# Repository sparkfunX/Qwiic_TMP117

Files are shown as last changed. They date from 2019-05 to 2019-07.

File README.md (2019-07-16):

SparkX Qwiic TMP117
========================================

SparkX High Precision Temperature Sensor - TMP117 (https://www.sparkfun.com/products/15413)

[*High Precision Temperature Sensor - TMP117 (Qwiic) (SPX-15413)*](https://www.sparkfun.com/products/15413)

The TMP117 is a high precision temperature Sensor with accuracy of up to +/-0.1 degrees celsius and an operating temperature range of -55°C to +150°C. It is NIST traceable and verified with equipment that is calibrated to ISO/IEC 17025 accredited standards. It has a very low power consumption with a supply range of 1.8V to 5.5V. 

The TMP117 address can be changed with an external jumper to 4 different addresses. There are 4 different conversion modes that it can read from, with continuous conversion, shutdown, and one shot conversion. There is also digital offset for system correction, programmable temperature limits, General-Purpose EEPROM, and selectable averaging. 

Repository Contents
-------------------

* **/Documents** - Data sheet for the TMP117
* **/Hardware** - Eagle design files (.brd, .sch)
* **/Production** - Production panel files (.brd) within the Production folder

License Information
-------------------

This product is _**open source**_! 

Please review the LICENSE.md file for license information. 

If you have any questions or concerns on licensing, please contact technical support on our [SparkFun forums](https://forum.sparkfun.com/viewforum.php?f=152).

Distributed as-is; no warranty is given.

- Your friends at SparkFun.

_<COLLABORATION CREDIT>_

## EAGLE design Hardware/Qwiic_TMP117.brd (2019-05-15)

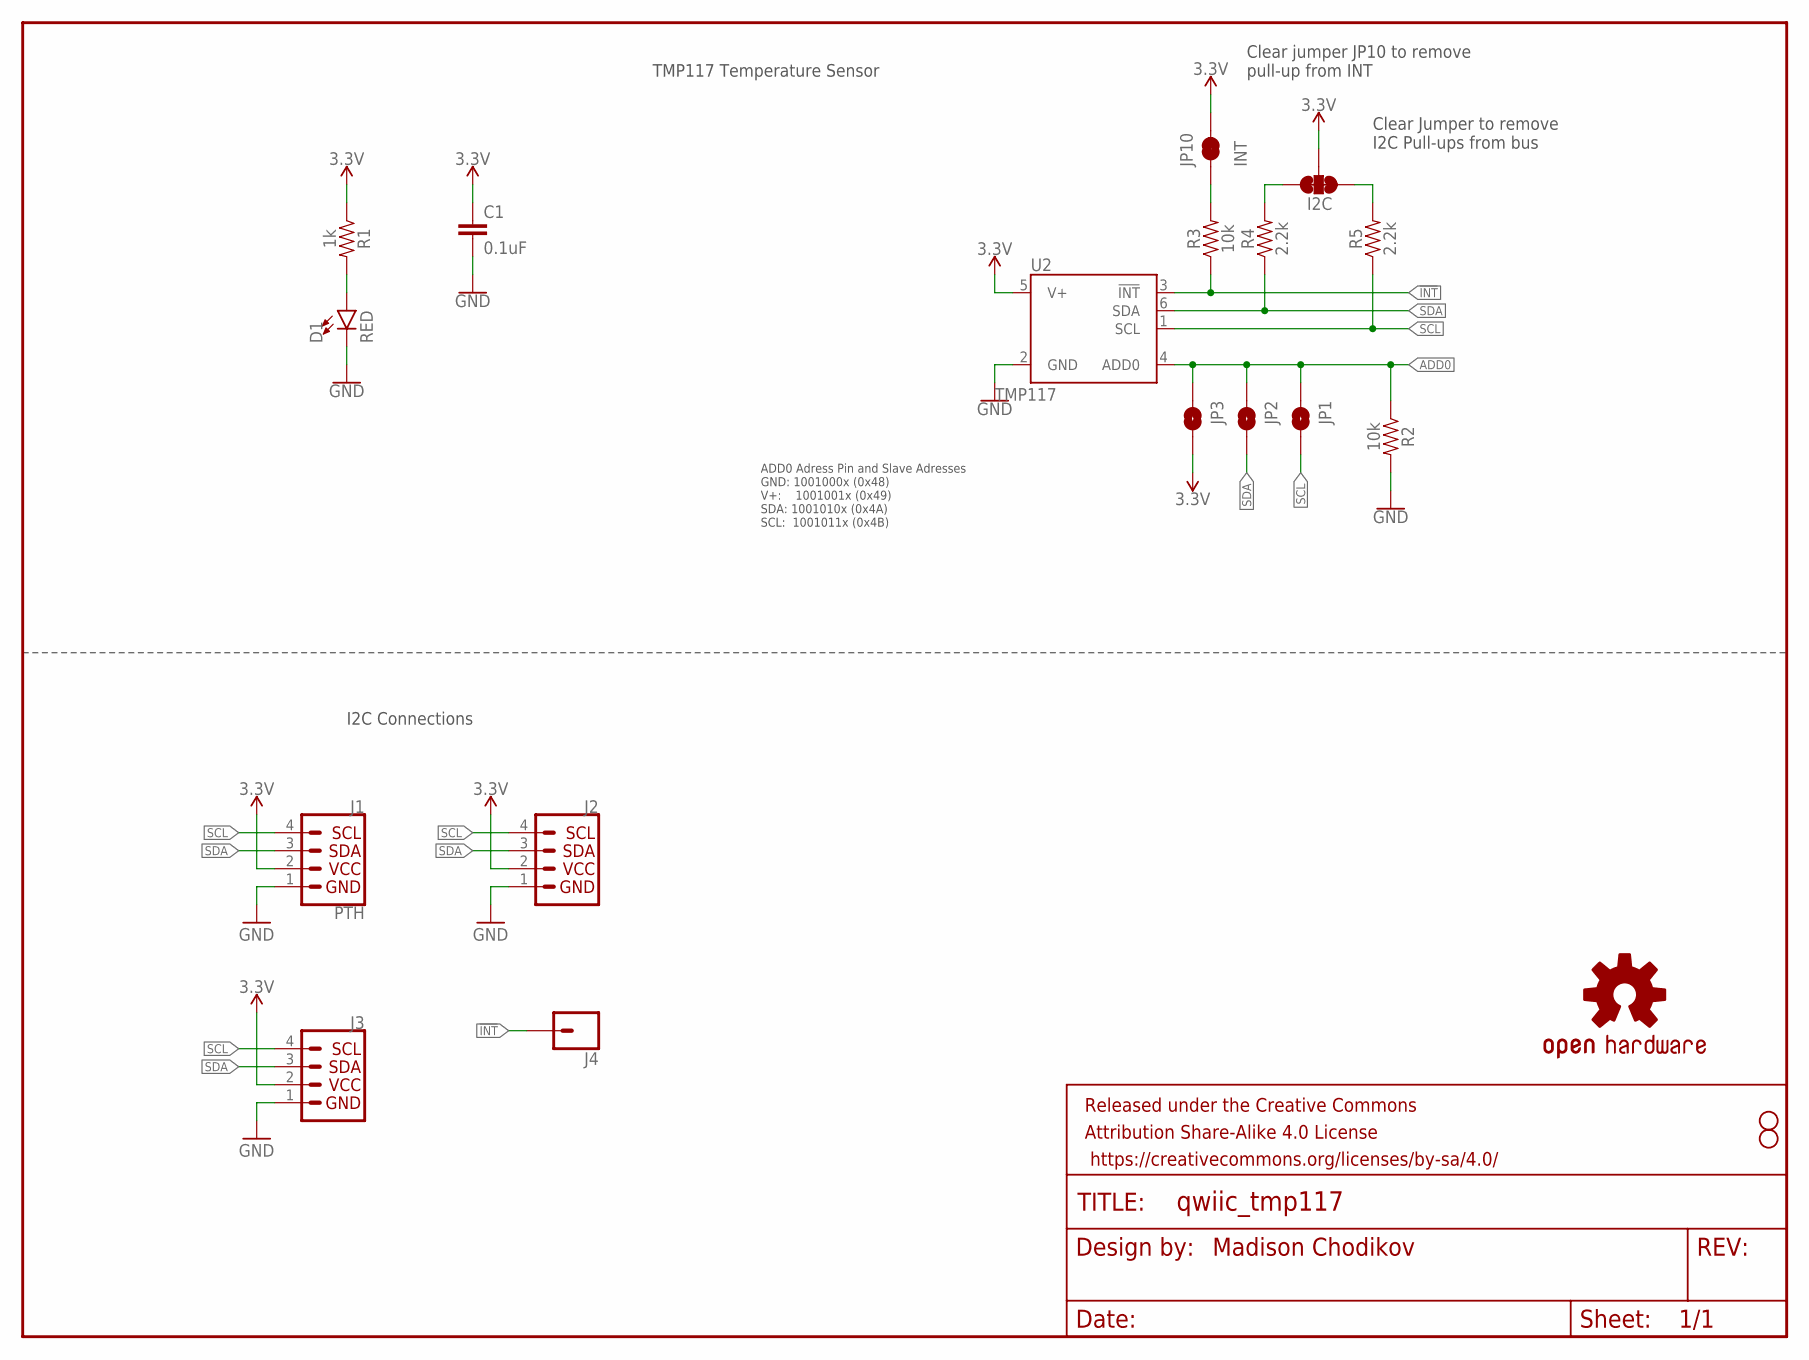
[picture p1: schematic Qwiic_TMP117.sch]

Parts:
C1: 0.1uF; 0603
D1: RED; LED-0603
FRAME1: FRAME-LETTER; CREATIVE_COMMONS
I2C: JUMPER-SMT_3_2-NC_TRACE_SILK; SMT-JUMPER_3_2-NC_TRACE_SILK
J1: PTH; 1X04_NO_SILK
J2, J3: QWIIC_CONNECTORJS-1MM; JST04_1MM_RA
J4: CONN_01PTH_NO_SILK_YES_STOP; 1X01_NO_SILK
JP1, JP2, JP3: JUMPER-SMT_2_NO_SILK; SMT-JUMPER_2_NO_SILK
JP8, JP9: STAND-OFF
JP10: INT; PAD-JUMPER-2-NC_BY_TRACE_YES_SILK
LOGO1: OSHW-LOGOMINI; OSHW-LOGO-MINI
R1: 1k; 0603
R2, R3: 10k; 0603
R4, R5: 2.2k; 0603
U2: TMP117

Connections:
3.3V: C1.1, I2C.2, J1.2 (VCC), J2.2, J3.2, JP3.2, JP10.2, R1.1, U2.5 (V+)
!INT: J4.1, R3.1, U2.3 (!INT)
ADD0: JP1.1, JP2.1, JP3.1, R2.1, U2.4 (ADD0)
GND: C1.2, D1.C, J1.1 (GND), J2.1, J3.1, R2.2, U2.2 (GND)
unnamed: D1.A, R1.2
unnamed: I2C.1, R5.2
unnamed: I2C.3, R4.2
unnamed: JP10.1, R3.2
SCL: J1.4 (SCL), J2.4, J3.4, JP1.2, R5.1, U2.1 (SCL)
SDA: J1.3 (SDA), J2.3, J3.3, JP2.2, R4.1, U2.6 (SDA)

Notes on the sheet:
I2C Connections
TMP117 Temperature Sensor
Madison Chodikov
Clear Jumper to remove I2C Pull-ups from bus
Clear jumper JP10 to remove pull-up from INT
ADD0 Adress Pin and Slave Adresses GND: 1001000x (0x48) V+: 1001001x (0x49) SDA: 1001010x (0x4A) SCL: 1001011x (0x4B)

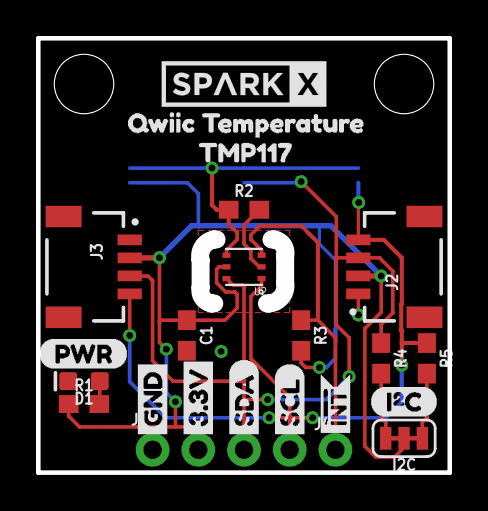
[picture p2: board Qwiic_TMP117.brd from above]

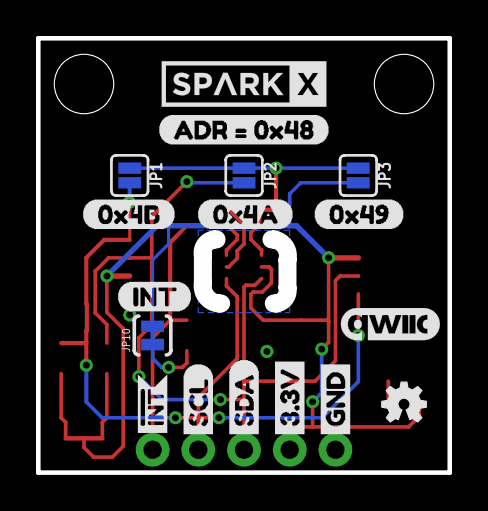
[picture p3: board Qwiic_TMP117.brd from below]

Board: 2 copper layers, 22.9 x 24.1 mm, 43 parts (17 on the bottom side), 10 nets.

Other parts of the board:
U$1: 0X4B1
U$2, U$17: SPARKX-MEDIUM
U$3, U$11: INT#-[<-04
U$4: TMP1171
U$5: 0X4A0
U$6: QWIIC_TEMPERATURE2
U$7: INT-()-04
U$8: 0X493
U$9, U$12: SCL-[)
U$10, U$23: GND-04
U$13, U$14: SDA-[)
U$15: QWIIC_5.5MM
U$18: ADR_#_0X484
U$19, U$22: 3.3V
U$20: PWR-()-04
U$21: I_SUPER2_C-()-04

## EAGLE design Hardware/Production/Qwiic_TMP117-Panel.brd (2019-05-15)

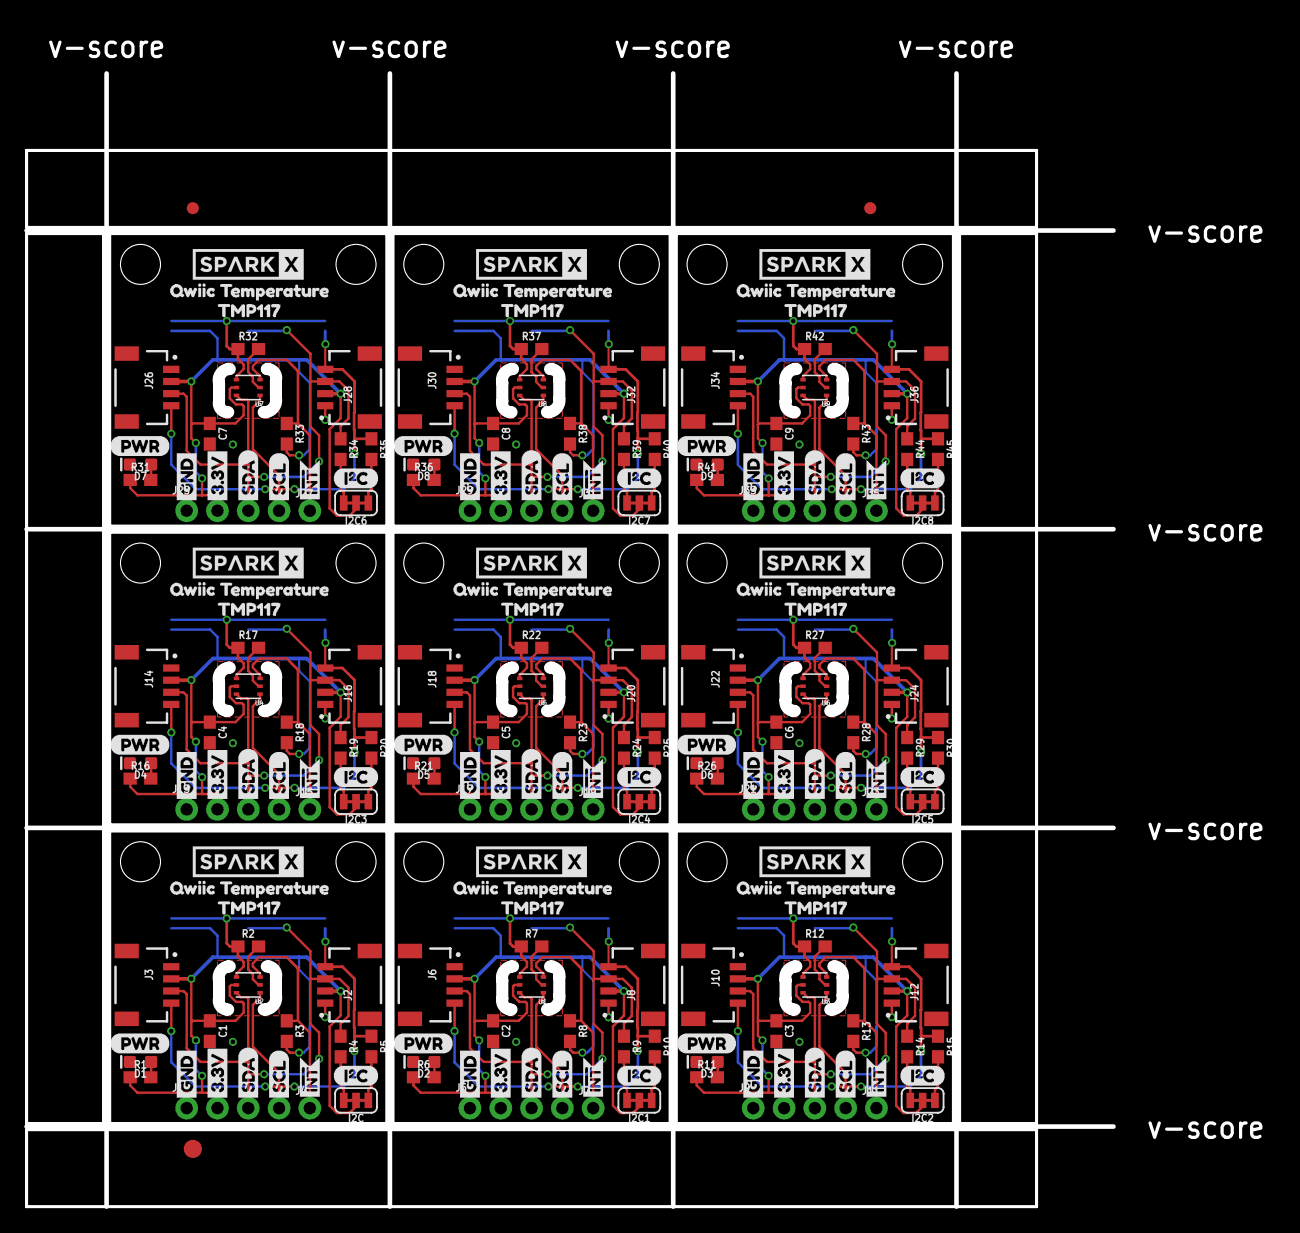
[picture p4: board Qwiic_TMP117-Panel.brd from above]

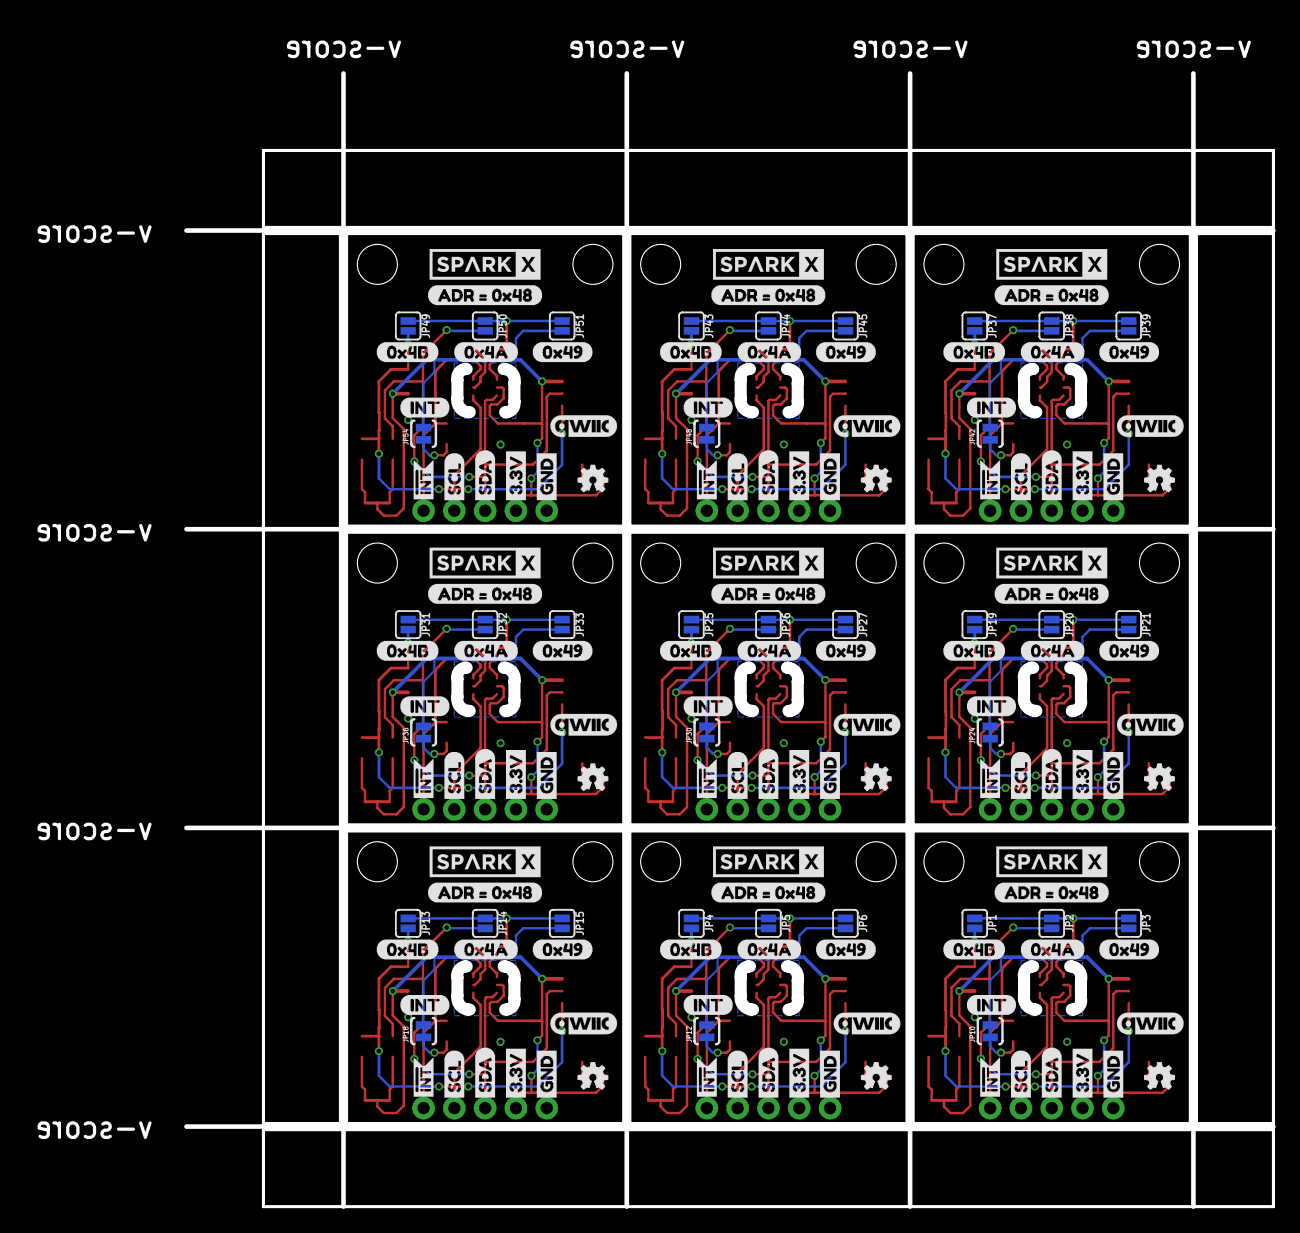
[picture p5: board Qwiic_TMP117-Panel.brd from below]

Board: 2 copper layers, 89.7 x 93.5 mm, 381 parts (153 on the bottom side), 90 nets.

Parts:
C1, C2, C3, C4, C5, C6, C7, C8, C9: 0.1uF; 0603
D1, D2, D3, D4, D5, D6, D7, D8, D9: RED; LED-0603
E$1, E$2: FIDUCIAL-1X2
E$3: FIDUCIAL-1.5X3
I2C, I2C1, I2C2, I2C3, I2C4, I2C5, I2C6, I2C7, I2C8: SMT-JUMPER_3_2-NC_TRACE_SILK
J1, J5, J9, J13, J17, J21, J25, J29, J33: PTH; 1X04_NO_SILK
J2, J3, J6, J8, J10, J12, J14, J16, J18, J20, J22, J24, J26, J28, J30, J32, J34, J36: JST04_1MM_RA
J4, J7, J11, J15, J19, J23, J27, J31, J35: 1X01_NO_SILK
JP1, JP2, JP3, JP4, JP5, JP6, JP13, JP14, JP15, JP19, JP20, JP21, JP25, JP26, JP27, JP31, JP32, JP33, JP37, JP38, JP39, JP43, JP44, JP45, JP49, JP50, JP51: SMT-JUMPER_2_NO_SILK
JP7, JP8, JP9, JP11, JP16, JP17, JP22, JP23, JP28, JP29, JP34, JP35, JP40, JP41, JP46, JP47, JP52, JP53: STAND-OFF
JP10, JP12, JP18, JP24, JP30, JP36, JP42, JP48, JP54: INT; PAD-JUMPER-2-NC_BY_TRACE_YES_SILK
LOGO1, LOGO2, LOGO3, LOGO4, LOGO5, LOGO6, LOGO7, LOGO8, LOGO9: OSHW-LOGOMINI; OSHW-LOGO-MINI
R1, R6, R11, R16, R21, R26, R31, R36, R41: 1k; 0603
R2, R3, R7, R8, R12, R13, R17, R18, R22, R23, R27, R28, R32, R33, R37, R38, R42, R43: 10k; 0603
R4, R5, R9, R10, R14, R15, R19, R20, R24, R25, R29, R30, R34, R35, R39, R40, R44, R45: 2.2k; 0603
U1, U2, U3, U4, U5, U6, U7, U8, U9: TMP117
U$1, U$40, U$62, U$84, U$106, U$128, U$150, U$172, U$194: 0X4B1
U$2, U$17, U$25, U$26, U$47, U$48, U$69, U$70, U$91, U$92, U$113, U$114, U$135, U$136, U$157, U$158, U$179, U$180: SPARKX-MEDIUM
U$3, U$11, U$27, U$30, U$49, U$52, U$71, U$74, U$93, U$96, U$115, U$118, U$137, U$140, U$159, U$162, U$181, U$184: INT#-[<-04
U$4, U$16, U$45, U$67, U$89, U$111, U$133, U$155, U$177: TMP1171
U$5, U$41, U$63, U$85, U$107, U$129, U$151, U$173, U$195: 0X4A0
U$6, U$24, U$46, U$68, U$90, U$112, U$134, U$156, U$178: QWIIC_TEMPERATURE2
U$7, U$28, U$50, U$72, U$94, U$116, U$138, U$160, U$182: INT-()-04
U$8, U$42, U$64, U$86, U$108, U$130, U$152, U$174, U$196: 0X493
U$9, U$12, U$29, U$37, U$51, U$59, U$73, U$81, U$95, U$103, U$117, U$125, U$139, U$147, U$161, U$169, U$183, U$191: SCL-[)
U$10, U$23, U$35, U$36, U$57, U$58, U$79, U$80, U$101, U$102, U$123, U$124, U$145, U$146, U$167, U$168, U$189, U$190: GND-04
U$13, U$14, U$38, U$39, U$60, U$61, U$82, U$83, U$104, U$105, U$126, U$127, U$148, U$149, U$170, U$171, U$192, U$193: SDA-[)
U$15, U$44, U$66, U$88, U$110, U$132, U$154, U$176, U$198: QWIIC_5.5MM
U$18, U$43, U$65, U$87, U$109, U$131, U$153, U$175, U$197: ADR_#_0X484
U$19, U$22, U$33, U$34, U$55, U$56, U$77, U$78, U$99, U$100, U$121, U$122, U$143, U$144, U$165, U$166, U$187, U$188: 3.3V
U$20, U$31, U$53, U$75, U$97, U$119, U$141, U$163, U$185: PWR-()-04
U$21, U$32, U$54, U$76, U$98, U$120, U$142, U$164, U$186: I_SUPER2_C-()-04

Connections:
3.3V: C1.1, I2C.2, J1.2, J2.2, J3.2, JP3.2, JP10.2, R1.1, U2.5
3.3V1: C2.1, I2C1.2, J5.2, J6.2, J8.2, JP6.2, JP12.2, R6.1, U1.5
3.3V2: C3.1, I2C2.2, J9.2, J10.2, J12.2, JP15.2, JP18.2, R11.1, U3.5
3.3V3: C4.1, I2C3.2, J13.2, J14.2, J16.2, JP21.2, JP24.2, R16.1, U4.5
3.3V4: C5.1, I2C4.2, J17.2, J18.2, J20.2, JP27.2, JP30.2, R21.1, U5.5
3.3V5: C6.1, I2C5.2, J21.2, J22.2, J24.2, JP33.2, JP36.2, R26.1, U6.5
3.3V6: C7.1, I2C6.2, J25.2, J26.2, J28.2, JP39.2, JP42.2, R31.1, U7.5
3.3V7: C8.1, I2C7.2, J29.2, J30.2, J32.2, JP45.2, JP48.2, R36.1, U8.5
3.3V8: C9.1, I2C8.2, J33.2, J34.2, J36.2, JP51.2, JP54.2, R41.1, U9.5
!INT: J4.1, R3.1, U2.3
!INT1: J7.1, R8.1, U1.3
!INT2: J11.1, R13.1, U3.3
!INT3: J15.1, R18.1, U4.3
!INT4: J19.1, R23.1, U5.3
!INT5: J23.1, R28.1, U6.3
!INT6: J27.1, R33.1, U7.3
!INT7: J31.1, R38.1, U8.3
!INT8: J35.1, R43.1, U9.3
ADD0: JP1.1, JP2.1, JP3.1, R2.1, U2.4
ADD1: JP4.1, JP5.1, JP6.1, R7.1, U1.4
ADD2: JP13.1, JP14.1, JP15.1, R12.1, U3.4
ADD3: JP19.1, JP20.1, JP21.1, R17.1, U4.4
ADD4: JP25.1, JP26.1, JP27.1, R22.1, U5.4
ADD5: JP31.1, JP32.1, JP33.1, R27.1, U6.4
ADD6: JP37.1, JP38.1, JP39.1, R32.1, U7.4
ADD7: JP43.1, JP44.1, JP45.1, R37.1, U8.4
ADD8: JP49.1, JP50.1, JP51.1, R42.1, U9.4
GND: C1.2, D1.C, J1.1, J2.1, J3.1, R2.2, U2.2
GND1: C2.2, D2.C, J5.1, J6.1, J8.1, R7.2, U1.2
GND2: C3.2, D3.C, J9.1, J10.1, J12.1, R12.2, U3.2
GND3: C4.2, D4.C, J13.1, J14.1, J16.1, R17.2, U4.2
GND4: C5.2, D5.C, J17.1, J18.1, J20.1, R22.2, U5.2
GND5: C6.2, D6.C, J21.1, J22.1, J24.1, R27.2, U6.2
GND6: C7.2, D7.C, J25.1, J26.1, J28.1, R32.2, U7.2
GND7: C8.2, D8.C, J29.1, J30.1, J32.1, R37.2, U8.2
GND8: C9.2, D9.C, J33.1, J34.1, J36.1, R42.2, U9.2
unnamed: D1.A, R1.2
unnamed: I2C.1, R5.2
unnamed: I2C.3, R4.2
unnamed: JP10.1, R3.2
unnamed: D2.A, R6.2
unnamed: I2C1.1, R10.2
unnamed: I2C1.3, R9.2
unnamed: JP12.1, R8.2
unnamed: D3.A, R11.2
unnamed: I2C2.1, R15.2
unnamed: I2C2.3, R14.2
unnamed: JP18.1, R13.2
unnamed: D4.A, R16.2
unnamed: I2C3.1, R20.2
unnamed: I2C3.3, R19.2
unnamed: JP24.1, R18.2
unnamed: D5.A, R21.2
unnamed: I2C4.1, R25.2
unnamed: I2C4.3, R24.2
unnamed: JP30.1, R23.2
unnamed: D6.A, R26.2
unnamed: I2C5.1, R30.2
unnamed: I2C5.3, R29.2
unnamed: JP36.1, R28.2
unnamed: D7.A, R31.2
unnamed: I2C6.1, R35.2
unnamed: I2C6.3, R34.2
unnamed: JP42.1, R33.2
unnamed: D8.A, R36.2
unnamed: I2C7.1, R40.2
unnamed: I2C7.3, R39.2
unnamed: JP48.1, R38.2
unnamed: D9.A, R41.2
unnamed: I2C8.1, R45.2
unnamed: I2C8.3, R44.2
unnamed: JP54.1, R43.2
SCL: J1.4, J2.4, J3.4, JP1.2, R5.1, U2.1
SCL1: J5.4, J6.4, J8.4, JP4.2, R10.1, U1.1
SCL2: J9.4, J10.4, J12.4, JP13.2, R15.1, U3.1
SCL3: J13.4, J14.4, J16.4, JP19.2, R20.1, U4.1
SCL4: J17.4, J18.4, J20.4, JP25.2, R25.1, U5.1
SCL5: J21.4, J22.4, J24.4, JP31.2, R30.1, U6.1
SCL6: J25.4, J26.4, J28.4, JP37.2, R35.1, U7.1
SCL7: J29.4, J30.4, J32.4, JP43.2, R40.1, U8.1
SCL8: J33.4, J34.4, J36.4, JP49.2, R45.1, U9.1
SDA: J1.3, J2.3, J3.3, JP2.2, R4.1, U2.6
SDA1: J5.3, J6.3, J8.3, JP5.2, R9.1, U1.6
SDA2: J9.3, J10.3, J12.3, JP14.2, R14.1, U3.6
SDA3: J13.3, J14.3, J16.3, JP20.2, R19.1, U4.6
SDA4: J17.3, J18.3, J20.3, JP26.2, R24.1, U5.6
SDA5: J21.3, J22.3, J24.3, JP32.2, R29.1, U6.6
SDA6: J25.3, J26.3, J28.3, JP38.2, R34.1, U7.6
SDA7: J29.3, J30.3, J32.3, JP44.2, R39.1, U8.6
SDA8: J33.3, J34.3, J36.3, JP50.2, R44.1, U9.6

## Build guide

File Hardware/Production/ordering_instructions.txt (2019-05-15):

panel size, 84x88mm
PCB thickness, 1.6mm
number of layers, 2
soldermask color, Black
silkscreen color, White
oz copper, 1oz
finish, HASL lead free
stencils, top
pcs per panel, 9
min trace width, 0.177800mm / 0.007000in
min drill size, 0.381000mm / 0.015000in

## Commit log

2019-04-19 Updated Schematic and Boar
    Fixed the board with the polygon and added a table to the schematic describing the pin addresses for ADD0
    [Qwiic_TMP117.brd, Qwiic_TMP117.sch]
2019-04-26 Updated PCB
    Fixed the board to meet the specifications for the data sheet's PCB considerations
    [Qwiic_TMP117.brd, Qwiic_TMP117.sch]
2019-04-26 Updated Board
    Fixed wiring and polygons
    [Qwiic_TMP117.brd, Qwiic_TMP117.sch]
2019-05-13 Final Design
    Final updated board with the production panelized board and Gerber files
    [Qwiic_TMP117-Panel.GBL, Qwiic_TMP117-Panel.GBO, Qwiic_TMP117-Panel.GBS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]
2019-05-15 Updated PCB
    PCB updated to meet the jlcpcb specs with new milling width
    [Qwiic_TMP117-Panel.brd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]
2019-05-23 Moved Arduino Files to own repo

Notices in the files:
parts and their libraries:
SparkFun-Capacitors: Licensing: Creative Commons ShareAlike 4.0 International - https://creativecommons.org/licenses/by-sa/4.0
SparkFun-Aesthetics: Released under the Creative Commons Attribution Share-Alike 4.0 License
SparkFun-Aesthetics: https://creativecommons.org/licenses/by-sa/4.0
